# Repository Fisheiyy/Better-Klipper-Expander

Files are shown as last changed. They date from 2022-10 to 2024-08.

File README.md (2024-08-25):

# THIS PROJECT HAS BEEN ABANDONED

# Better Klipper Expander
 A RP2040 based 3D Printer Port Expander with 6 Fan Ports, Selectable Fan Voltage (24V/5V) (3 Fans per Voltage Selection Header), 2 Thermistor ports (1 with PT1000 Support), and a Positive Driven Fan Port (FAN5) for CPAP Fan Drivers.

## [iBOM](https://htmlpreview.github.io/?https://github.com/Fisheiyy/Better-Klipper-Expander/blob/main/ibom.html), [BOM](https://docs.google.com/spreadsheets/d/1mPUtkNYWScB2l85k0YQtJtEaqjWuknqn7hNMz57VFFw/edit#gid=1487594272), [Schematic](https://github.com/Fisheiyy/Better-Klipper-Expander/blob/main/better-klipper-expander.pdf) <br><br> Inspired by [Klipper Expander](https://github.com/timmit99/Klipper-Expander) by [timmit99](https://github.com/timmit99) <br> Made for the Voron & Klipper Communities
<hr>

# PICTURES
 ### V1 Picture
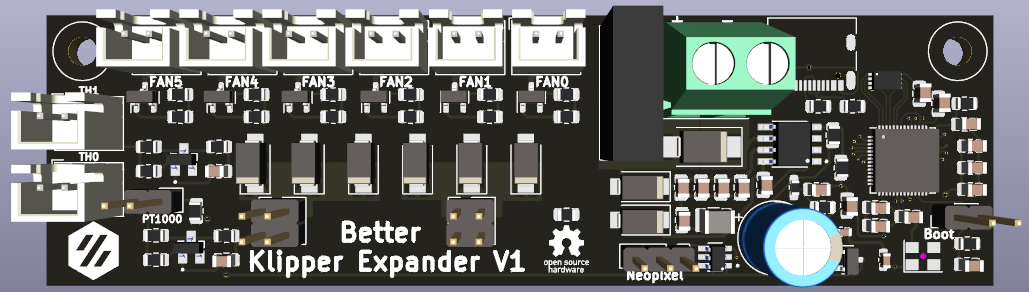
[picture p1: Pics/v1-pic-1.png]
Better Klipper Expander V1 Picture
 
<hr>

# LICENSE
 #### **You CANNOT use anything in this repo for Commercial Use without EXPLICIT PERMISSION**
*You can contact me if you have any questions regarding this.*
 ## This repository is under the [CC-BY-NC-SA-4.0](https://creativecommons.org/licenses/by-nc-sa/4.0) which states:
 ### You are free to:
   - Share — copy and redistribute the material in any medium or format
   - Adapt — remix, transform, and build upon the material
 ### Under the following terms:
  - Attribution — You **must** give **appropriate credit**, **provide a link to the license**, and **indicate if changes were made**. You may do so in any reasonable manner, but not in any way that suggests the licensor endorses you or your use.
  - NonCommercial — You may **not** use the material for **commercial purposes.**
  - ShareAlike — If you remix, transform, or build upon the material, you **must distribute your contributions under the same license as the original.**

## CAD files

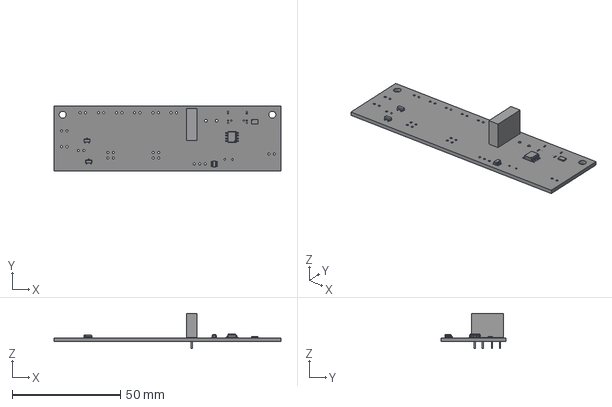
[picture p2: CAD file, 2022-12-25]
better-klipper-expander.step
105.0 x 30.0 x 16.3 mm
_autosave-better-klipper-expander PCB

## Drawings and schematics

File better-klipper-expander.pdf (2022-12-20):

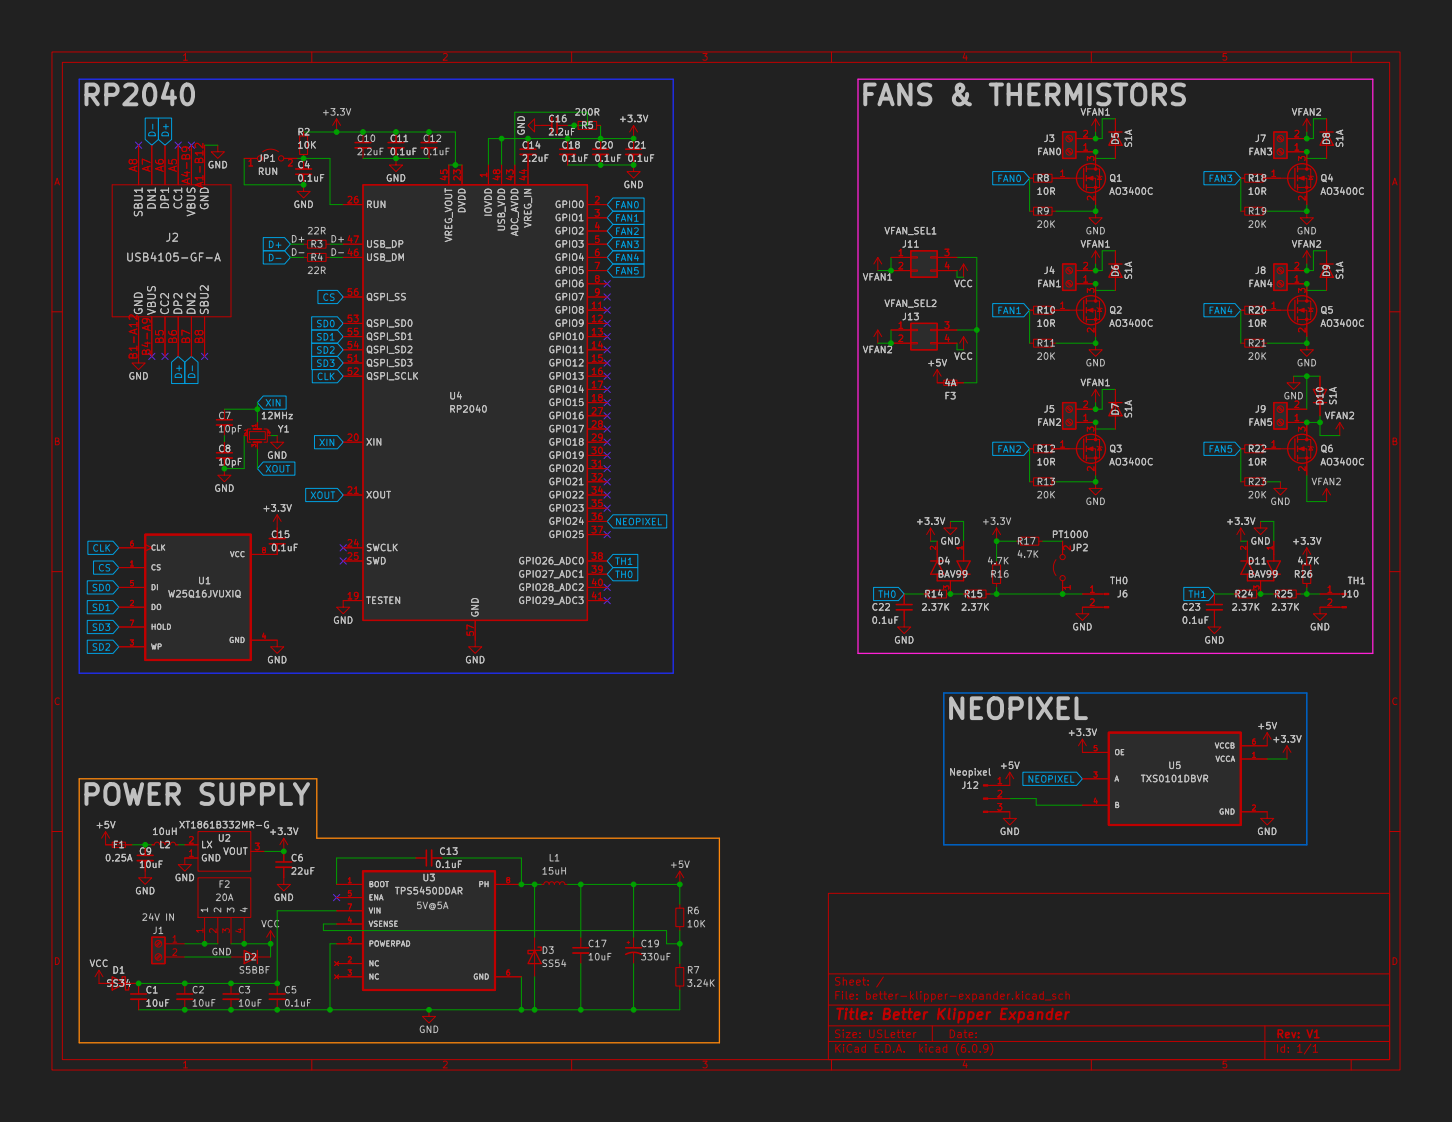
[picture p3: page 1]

1 GPIO8 11 GPIO9 12 GPIO10 13 GPIO11 14 GPIO12 15 GPIO13 16 GPIO14 17 GPIO15 18 TESTEN 19 GPIO0 2 XIN 20 XOUT 21 DVDD 23 SWCLK 24 SWD 25 RUN 26 GPIO16 27 GPIO17 28 GPIO18 29 GPIO1 3 GPIO19 30 GPIO20 31 GPIO21 32 GPIO22 34 GPIO23 35 GPIO24 36 GPIO25 37 GPIO26_ADC0 38 GPIO27_ADC1 39 GPIO2 4 GPIO28_ADC2 40 GPIO29_ADC3 41 ADC_AVDD 43 VREG_IN 44 VREG_VOUT 45 USB_DM 46 USB_DP 47 USB_VDD 48 GPIO3 5 QSPI_SD3 51 QSPI_SCLK 52 QSPI_SD0 53 QSPI_SD2 54 QSPI_SD1 55 QSPI_SS 56 GND 57 GPIO4 6 GPIO5 7 GPIO6 8 GPIO7 9 U4RP2040 GND GND A1-B12 VBUS A4-B9 CC1 A5 DP1 A6 DN1 A7 SBU1 A8 GND B1-A12 VBUS B4-A9 CC2 B5 DP2 B6 DN2 B7 SBU2 B8

1 GPIO8 11 GPIO9 12 GPIO10 13 GPIO11 14 GPIO12 15 GPIO13 16 GPIO14 17 GPIO15 18 TESTEN 19 GPIO0 2 XIN 20 XOUT 21 DVDD 23 SWCLK 24 SWD 25 RUN 26 GPIO16 27 GPIO17 28 GPIO18 29 GPIO1 3 GPIO19 30 GPIO20 31 GPIO21 32 GPIO22 34 GPIO23 35 GPIO24 36 GPIO25 37 GPIO26_ADC0 38 GPIO27_ADC1 39 GPIO2 4 GPIO28_ADC2 40 GPIO29_ADC3 41 ADC_AVDD 43 VREG_IN 44 VREG_VOUT 45 USB_DM 46 USB_DP 47 USB_VDD 48 GPIO3 5 QSPI_SD3 51 QSPI_SCLK 52 QSPI_SD0 53 QSPI_SD2 54 QSPI_SD1 55 QSPI_SS 56 GND 57 GPIO4 6 GPIO5 7 GPIO6 8 GPIO7 9 GND

File: better-klipper-expander.kicad_sch Sheet: /
Id: 1/1 Title: Better Klipper Expander

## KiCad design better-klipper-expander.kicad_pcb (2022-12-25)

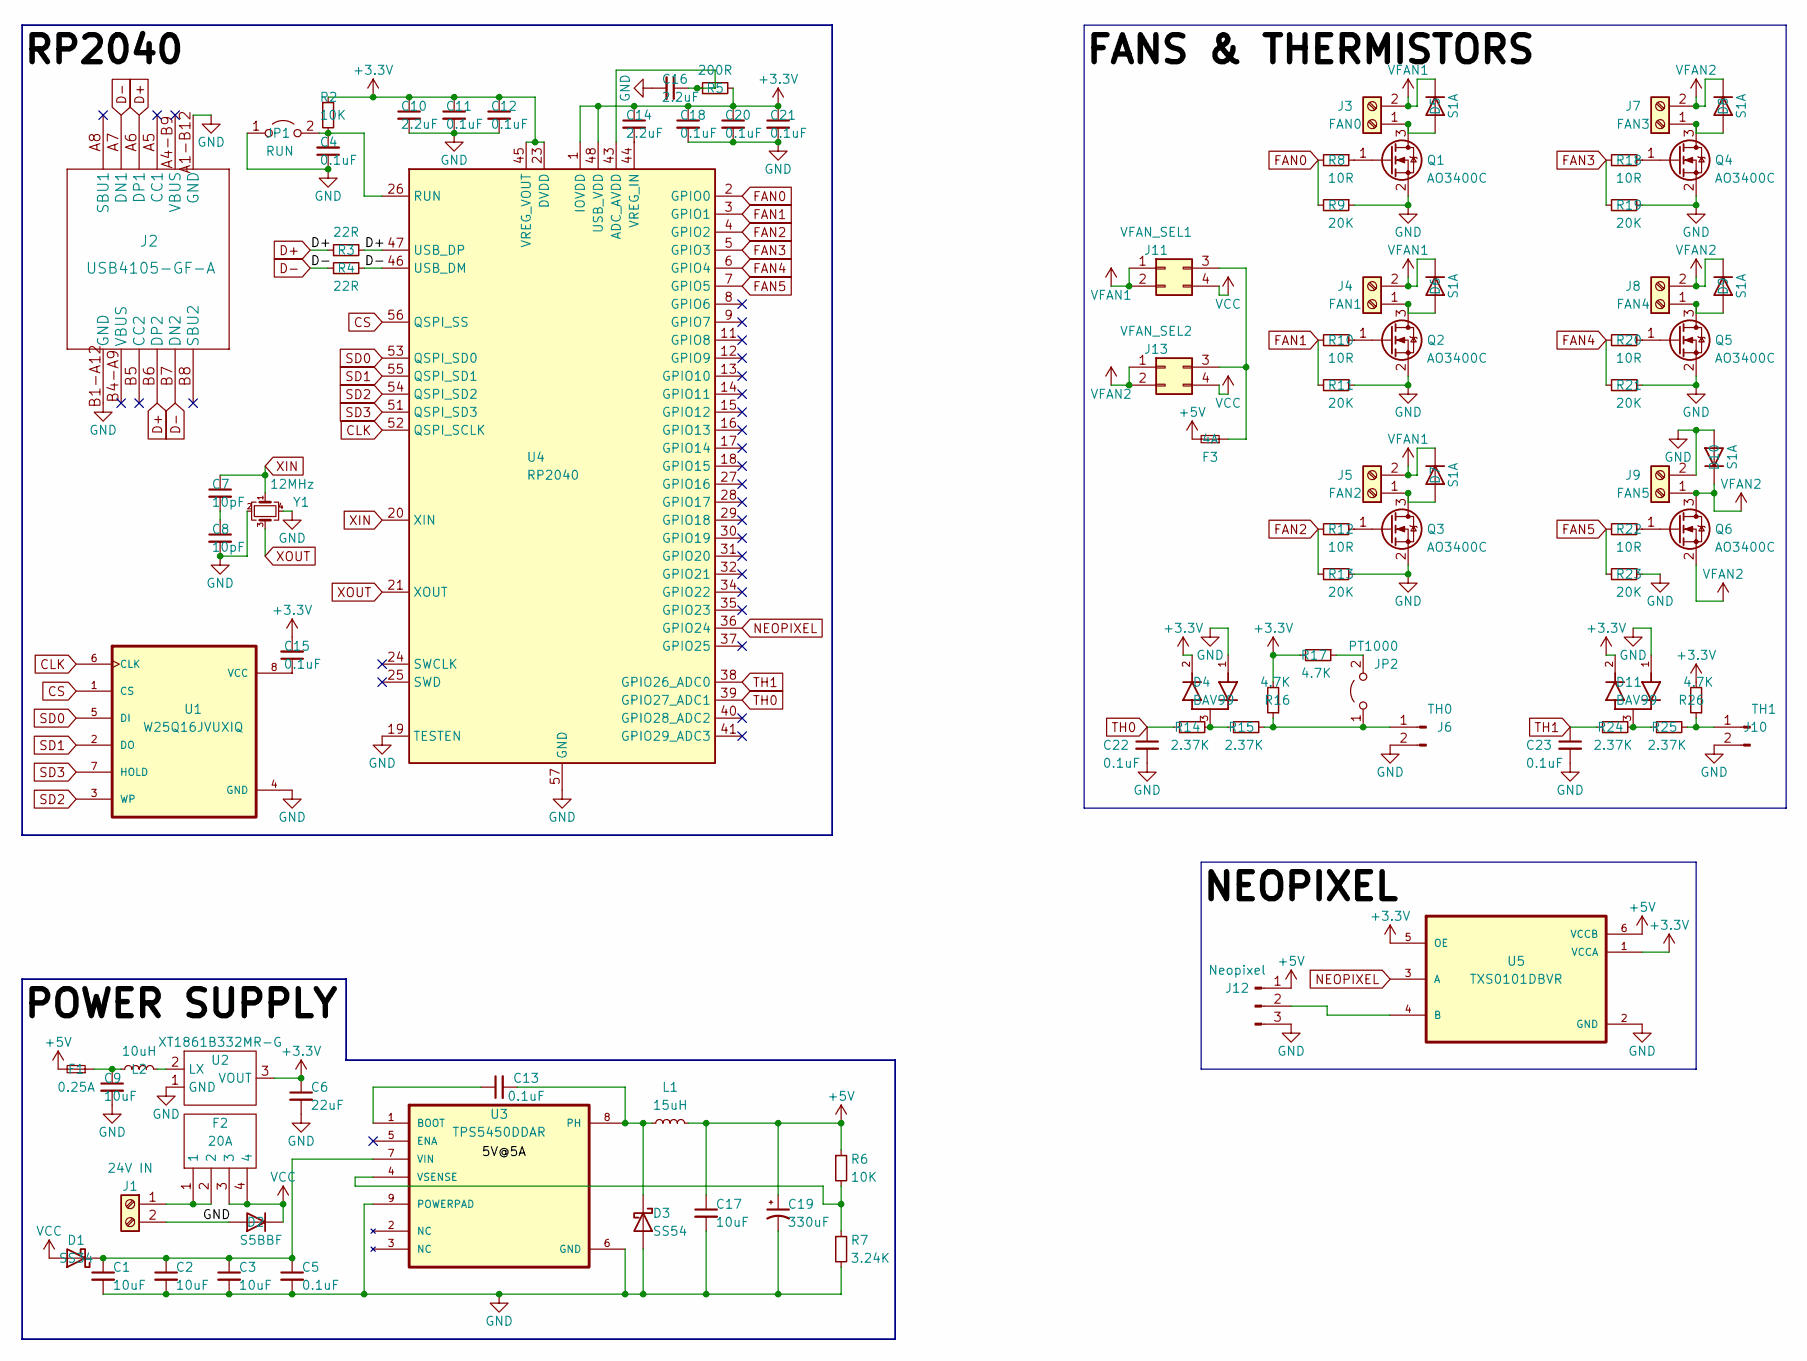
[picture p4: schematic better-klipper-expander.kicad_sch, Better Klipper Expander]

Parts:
C1, C2, C3, C9, C17: 10uF; C_0805_2012Metric
C4, C5, C11, C12, C13, C15, C18, C20, C21, C22, C23: 0.1uF; C_0805_2012Metric
C6: 22uF; C_0805_2012Metric
C7, C8: 10pF; C_0603_1608Metric
C10, C14, C16: 2.2uF; C_0805_2012Metric
C19: 330uF; CP_Radial_D8.0mm_P3.50mm
D1: SS34; D_SMA
D2: S5BBF; D_SMB_Handsoldering
D3: SS54; D_SMA
D4, D11: BAV99; DIO_BAV99
D5, D6, D7, D8, D9, D10: S1A; D_SMA
F1: 0.25A; Fuse_0603_1608Metric_Pad1.05x0.95mm_HandSolder
F2: 20A; 01000063Z
F3: 4A; Fuse_0805_2012Metric
J1: 24V IN; TerminalBlock_Phoenix_MKDS-1,5-2_1x02_P5.00mm_Horizontal
J2: USB4105-GF-A
J3: FAN0; JST_XH_B2B-XH-A_1x02_P2.50mm_Vertical
J4: FAN1; JST_XH_B2B-XH-A_1x02_P2.50mm_Vertical
J5: FAN2; JST_XH_B2B-XH-A_1x02_P2.50mm_Vertical
J6: TH0; JST_XH_B2B-XH-A_1x02_P2.50mm_Vertical
J7: FAN3; JST_XH_B2B-XH-A_1x02_P2.50mm_Vertical
J8: FAN4; JST_XH_B2B-XH-A_1x02_P2.50mm_Vertical
J9: FAN5; JST_XH_B2B-XH-A_1x02_P2.50mm_Vertical
J10: TH1; JST_XH_B2B-XH-A_1x02_P2.50mm_Vertical
J11: VFAN_SEL1; PinHeader_2x02_P2.54mm_Vertical
J12: Neopixel; PinHeader_1x03_P2.54mm_Vertical
J13: VFAN_SEL2; PinHeader_2x02_P2.54mm_Vertical
JP1: RUN; PinHeader_1x02_P2.54mm_Vertical
JP2: PT1000; PinHeader_1x02_P2.54mm_Vertical
L1: 15uH; L_1210_3225Metric
L2: 10uH; Fuse_0805_2012Metric
Q1, Q2, Q3, Q4, Q5, Q6: AO3400C; SOT-23
R2, R6: 10K; R_0805_2012Metric
R3, R4: 22R; R_0805_2012Metric
R5: 200R; R_0805_2012Metric
R7: 3.24K; R_0805_2012Metric
R8, R10, R12, R18, R20, R22: 10R; R_0805_2012Metric
R9, R11, R13, R19, R21, R23: 20K; R_0805_2012Metric
R14, R15, R24, R25: 2.37K; R_0805_2012Metric
R16, R17, R26: 4.7K; R_0805_2012Metric
U1: W25Q16JVUXIQ; SON50P300X200X60-9N
U2: XT1861B332MR-G; SOT-23
U3: TPS5450DDAR; VREG_LM5017MR/NOPB
U4: RP2040; QFN-56-1EP_7x7mm_P0.4mm_EP3.2x3.2mm
U5: TXS0101DBVR; SOT95P280X145-6N
Y1: 12MHz; Oscillator_SMD_SeikoEpson_SG8002CE-4Pin_3.2x2.5mm

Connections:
+3.3V: C6.1, C10.1, C11.1, C12.1, C14.1, C15.2, C18.1, C20.1, C21.1, D4.2, D11.2, R2.1, R5.2, R16.2, R17.2, R26.2, U2.3 (VOUT), U4.1 (IOVDD), U4.10 (IOVDD), U4.22 (IOVDD), U4.23 (DVDD), U4.33 (IOVDD), U4.42 (IOVDD), U4.45 (VREG_VOUT), U4.48 (USB_VDD), U4.49 (IOVDD), U4.50 (DVDD), U5.1 (VCCA), U5.5 (OE)
+5V: C17.1, C19.1, F1.2, F3.2, J12.1, L1.2, R6.1, U5.6 (VCCB)
CLK: U1.6 (CLK), U4.52 (QSPI_SCLK)
CS: U1.1 (CS), U4.56 (QSPI_SS)
D+: J2.A6 (DP1), J2.B6 (DP2), R3.1, R3.2, U4.47 (USB_DP)
D-: J2.A7 (DN1), J2.B7 (DN2), R4.1, R4.2, U4.46 (USB_DM)
FAN0: R8.2, R9.2, U4.2 (GPIO0)
FAN1: R10.2, R11.2, U4.3 (GPIO1)
FAN2: R12.2, R13.2, U4.4 (GPIO2)
FAN3: R18.2, R19.2, U4.5 (GPIO3)
FAN4: R20.2, R21.2, U4.6 (GPIO4)
FAN5: R22.2, R23.2, U4.7 (GPIO5)
GND: C1.2, C2.2, C3.2, C4.1, C5.2, C6.2, C8.2, C9.2, C10.2, C11.2, C12.2, C16.2, C17.2, C18.2, C19.2, C20.2, C21.2, C22.2, C23.2, D2.1 (A), D3.2 (A), D4.1, D10.2 (A), D11.1, J1.2, J2.A1-B12 (GND), J2.B1-A12 (GND), J6.2, J9.2, J10.2, J12.3, JP1.1 (A), Q1.2 (S), Q2.2 (S), Q3.2 (S), Q4.2 (S), Q5.2 (S), R7.2, R9.1, R11.1, R13.1, R19.1, R21.1, R23.1, U1.4 (GND), U2.1 (GND), U3.6 (GND), U3.9 (POWERPAD), U4.19 (TESTEN), U4.57 (GND), U5.2 (GND), Y1.2, Y1.4
NEOPIXEL: U4.36 (GPIO24), U5.3 (A)
unnamed: C1.1, C2.1, C3.1, C5.1, D1.1 (K), U3.7 (VIN)
unnamed: C4.2, JP1.2 (B), R2.2, U4.26 (RUN)
unnamed: C7.2, C8.1
unnamed: C9.1, F1.1, L2.1
unnamed: C13.1, U3.1 (BOOT)
unnamed: C13.2, D3.1 (K), L1.1, U3.8 (PH)
unnamed: C14.2, U4.44 (VREG_IN)
unnamed: C15.1, U1.8 (VCC)
unnamed: C16.1, R5.1, U4.43 (ADC_AVDD)
unnamed: D4.3, R14.2, R15.1
unnamed: D5.2 (A), J3.1, Q1.3 (D)
unnamed: D6.2 (A), J4.1, Q2.3 (D)
unnamed: D7.2 (A), J5.1, Q3.3 (D)
unnamed: D8.2 (A), J7.1, Q4.3 (D)
unnamed: D9.2 (A), J8.1, Q5.3 (D)
unnamed: D11.3, R24.2, R25.1
unnamed: F2.1, F2.2, J1.1
unnamed: F3.1, J11.3, J13.3
unnamed: J6.1, JP2.1 (A), R15.2, R16.1
unnamed: J10.1, R25.2, R26.1
unnamed: J12.2, U5.4 (B)
unnamed: JP2.2 (B), R17.1
unnamed: L2.2, U2.2 (LX)
unnamed: Q1.1 (G), R8.1
unnamed: Q2.1 (G), R10.1
unnamed: Q3.1 (G), R12.1
unnamed: Q4.1 (G), R18.1
unnamed: Q5.1 (G), R20.1
unnamed: Q6.1 (G), R22.1
unnamed: R6.2, R7.1, U3.4 (VSENSE)
SD0: U1.5 (DI), U4.53 (QSPI_SD0)
SD1: U1.2 (DO), U4.55 (QSPI_SD1)
SD2: U1.3 (WP), U4.54 (QSPI_SD2)
SD3: U1.7 (HOLD), U4.51 (QSPI_SD3)
TH0: C22.1, R14.1, U4.39 (GPIO27_ADC1)
TH1: C23.1, R24.1, U4.38 (GPIO26_ADC0)
VCC: D1.2 (A), D2.2 (K), F2.3, F2.4, J11.4, J13.4
XIN: C7.1, U4.20 (XIN), Y1.1
XOUT: U4.21 (XOUT), Y1.3

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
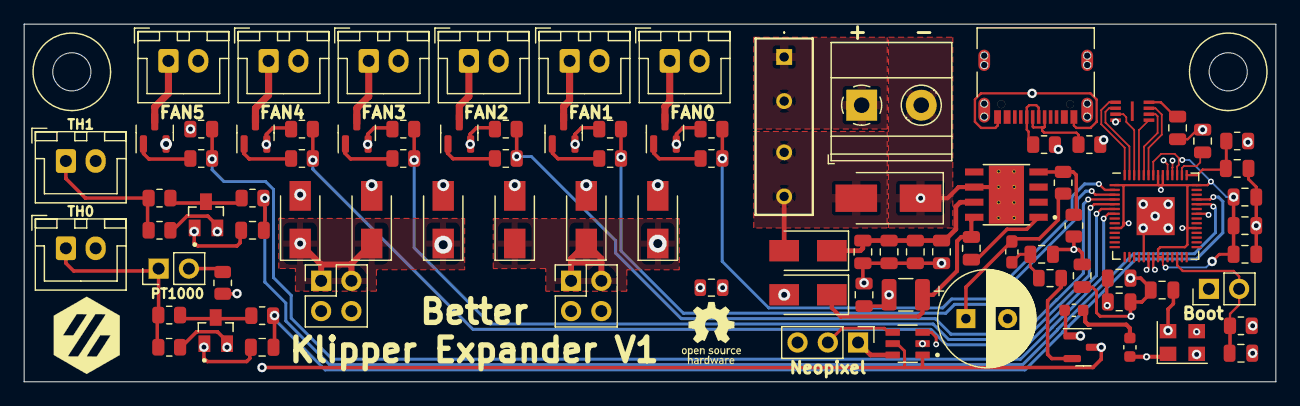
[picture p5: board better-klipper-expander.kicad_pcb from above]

Board: 4 copper layers, 105.0 x 30.0 mm, 93 parts (0 on the bottom side), 54 nets.

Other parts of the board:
H1, H2: MountingHole; MountingHole_3.2mm_M3

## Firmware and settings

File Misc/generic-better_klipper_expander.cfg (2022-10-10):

# This file contains common pin mappings for the Better Klipper Expander.
# To use this config, the firmware should be compiled for the RP2040 with
# USB communication.

# The "make flash" command does not work on the Better Klipper Expander. Instead,
# after running "make", copy the generated "out/klipper.uf2" file
# to the mass storage device in RP2040 boot mode

# See docs/Config_Reference.md for a description of parameters.

[mcu]
serial: /dev/serial/by-id/usb-Klipper_Klipper_firmware_12345-if00

[fan0]
pin: gpio0

[fan1]
pin: gpio1

[fan2]
pin: gpio2

[fan3]
pin: gpio3

[fan4]
pin: gpio4

[fan5]
pin: gpio5

[thermistor th0]
sensor_pin: gpio26
sensor_type: EPCOS 100K B57560G104F
#sensor_type: PT1000
#pullup_resistor: 4700

[thermistor th1]
sensor_pin: gpio27
sensor_type: EPCOS 100K B57560G104F

[neopixel neopixel]
pin: gpio24
chain_count:
#   The number of Neopixel chips that are "daisy chained" to the
#   provided pin. The default is 1 (which indicates only a single
#   Neopixel is connected to the pin).
color_order: GRB
#   Set the pixel order required by the LED hardware (using a string
#   containing the letters R, G, B, W with W optional). Alternatively,
#   this may be a comma separated list of pixel orders - one for each
#   LED in the chain. The default is GRB.
initial_RED: 0.0
initial_GREEN: 0.0
initial_BLUE: 0.0
initial_WHITE: 0.0

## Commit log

2022-10-06 Finished V1
    [better-klipper-expander-B_Cu.gbr, better-klipper-expander-B_Mask.gbr, better-klipper-expander-B_Paste.gbr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]
2022-10-08 Vias, Widths, and Organization...
    [better-klipper-expander-B_Cu.gbr, better-klipper-expander-B_Mask.gbr, better-klipper-expander-B_Paste.gbr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]
2022-10-10 3 fans per voltage selection now
    [better-klipper-expander-B_Cu.gbr, better-klipper-expander-B_Mask.gbr, better-klipper-expander-B_Paste.gbr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]
2022-10-11 remove silkscreen things i forgot
    [better-klipper-expander-B_Cu.gbr, better-klipper-expander-B_Mask.gbr, better-klipper-expander-B_Paste.gbr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]
2022-11-19 Minor updates
    [better-klipper-expander-B_Cu.gbr, better-klipper-expander-B_Mask.gbr, better-klipper-expander-B_Paste.gbr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]
2022-12-20 change flash + fix major problem + minor cleanup
    [better-klipper-expander-B_Cu.gbr, better-klipper-expander-B_Mask.gbr, better-klipper-expander-B_Paste.gbr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]
2022-12-25 Update Readme + Re-export Gerbers + Pics
    [better-klipper-expander-B_Cu.gbr, better-klipper-expander-B_Mask.gbr, better-klipper-expander-B_Paste.gbr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]
2022-12-25 Move Flash Closer to RP2040
    [better-klipper-expander-B_Cu.gbr, better-klipper-expander-B_Mask.gbr, better-klipper-expander-B_Paste.gbr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]

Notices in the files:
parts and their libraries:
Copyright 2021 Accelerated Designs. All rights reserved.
